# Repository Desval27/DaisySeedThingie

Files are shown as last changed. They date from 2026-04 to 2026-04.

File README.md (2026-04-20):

# Prototyping Carrier Board for the Daisy Seed™ 

https://electro-smith.com/products/daisy-seed

This PCB is designed to breakout all the PINs of the Daisy Seed along with additional components such as push buttons, LEDs, potentiometers, I<sup>2</sup>C, and SD card interfaces along with enough room for a typical 830 point breadboard.  

All 40 Daisy PINs are available on both sides of the board with those on the left being mirrored/inverted for additional flexibility.

[Interactive Bill of Materials (BOM)](https://github.com/Desval27/DaisySeedThingie/blob/main/bom/ibom.html)

## Ready to Order Gerber Files
- [Default](hardware/gerber_to_order/DaisySeedThingie_254.0x167.64mm_for_Default.zip)
- [Elecrow](hardware/gerber_to_order/DaisySeedThingie_254.0x167.64mm_for_Elecrow.zip)
- [FusionPCB](hardware/gerber_to_order/DaisySeedThingie_254.0x167.64mm_for_FusionPCB.zip)
- [JLCPCB](hardware/gerber_to_order/DaisySeedThingie_254.0x167.64mm_for_JLCPCB.zip)
- [PCBWay](hardware/gerber_to_order/DaisySeedThingie_254.0x167.64mm_for_PCBWay.zip)

## Status

Repository updated to Revision B.  Revision B is currently being tested.

Revsion A has several issues that are being corrected in Revision B.  Revision B is close to being finished.

- Due to footprint and learning issues no 3.5mm jacks are actually connected.  They can be hacked on the backside.
- All potentiometers are wired backwards.  CCW increases the voltage at the wiper while CW decreases it.

## Notes:
- Push buttons are connected on one side to GND to be used with input pullup GPIO pins.
- Potentiomenters are prewired on on the CW & CCW sides to +3V3 and GND.
- Audio in/out jacks are directly connected to the Seed's audio in/out pins.
   If the mono audio in jacks are used left audio in is normalized to right audio in so that they will both be available for processing by the seed if nothing is connected to right audio in.
- JST connectors are provided to breakout the Audio in/out and MIDI in/out signals to external jacks (1/4" Phono, 5-pin DIN, etc.).
- Jumpers are provided to change the configuration between TRS MIDI-A and TRS MIDI-B.  The default configuration is MIDI-A.  If MIDI-B is desired then the jumpers for MIDI-A need to be cut and those for MIDI-B bridged.

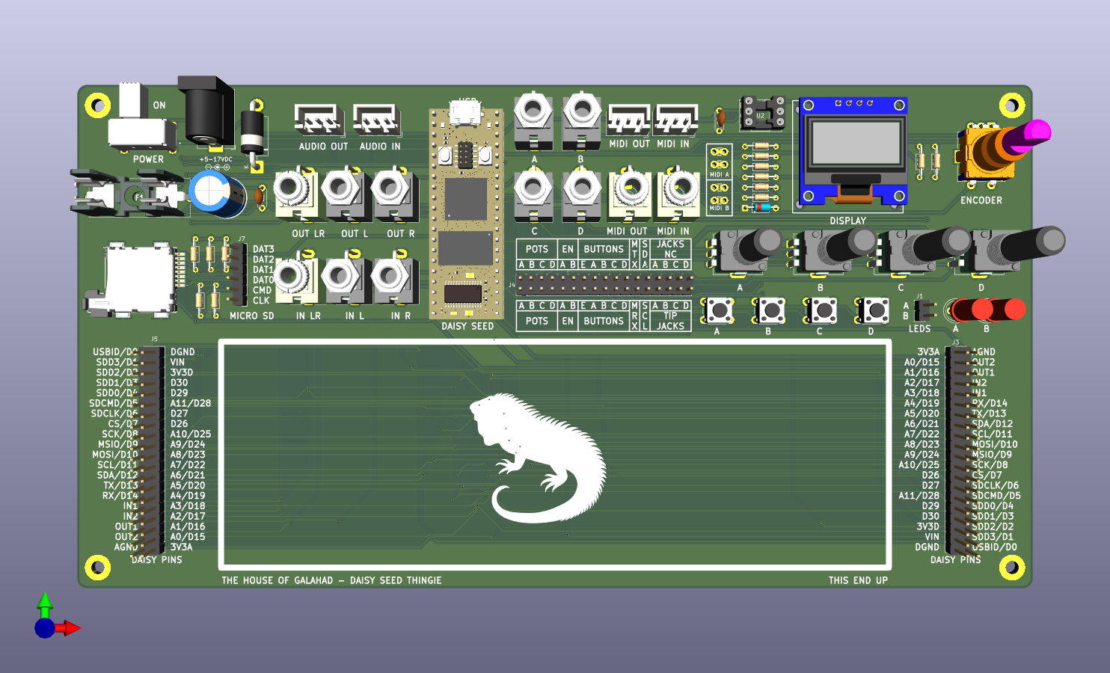
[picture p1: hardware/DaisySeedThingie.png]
Rendered PCB Image


## ⚠️ Disclaimer

This project is provided **"as is"**, without warranty of any kind, express or implied,
including but not limited to the warranties of merchantability, fitness for a
particular purpose, and noninfringement.

This is a DIY electronics project intended for educational and experimental use.
Use at your own risk.

The author assumes **no responsibility or liability** for any damage, injury, or loss
resulting from the use or misuse of this design, including but not limited to:

* Damage to connected equipment (Eurorack modules, power supplies, computers, etc.)
* Incorrect assembly or wiring
* Use with incompatible voltages or signal levels
* Personal injury

### Electrical Safety

This project may interface with:

* ±12V Eurorack power rails
* External control voltages (CV)
* Digital and analog circuitry

Improper handling may result in damage or unsafe conditions.

You are responsible for:

* Verifying all connections before powering the system
* Ensuring correct polarity of power connections
* Confirming voltage ranges and signal compatibility
* Using appropriate protection circuits where necessary

### No Guarantees

Schematics, PCB layouts, and code are provided for reference only.
They may contain errors, omissions, or design flaws.

**Always review and validate the design before building or using it.**

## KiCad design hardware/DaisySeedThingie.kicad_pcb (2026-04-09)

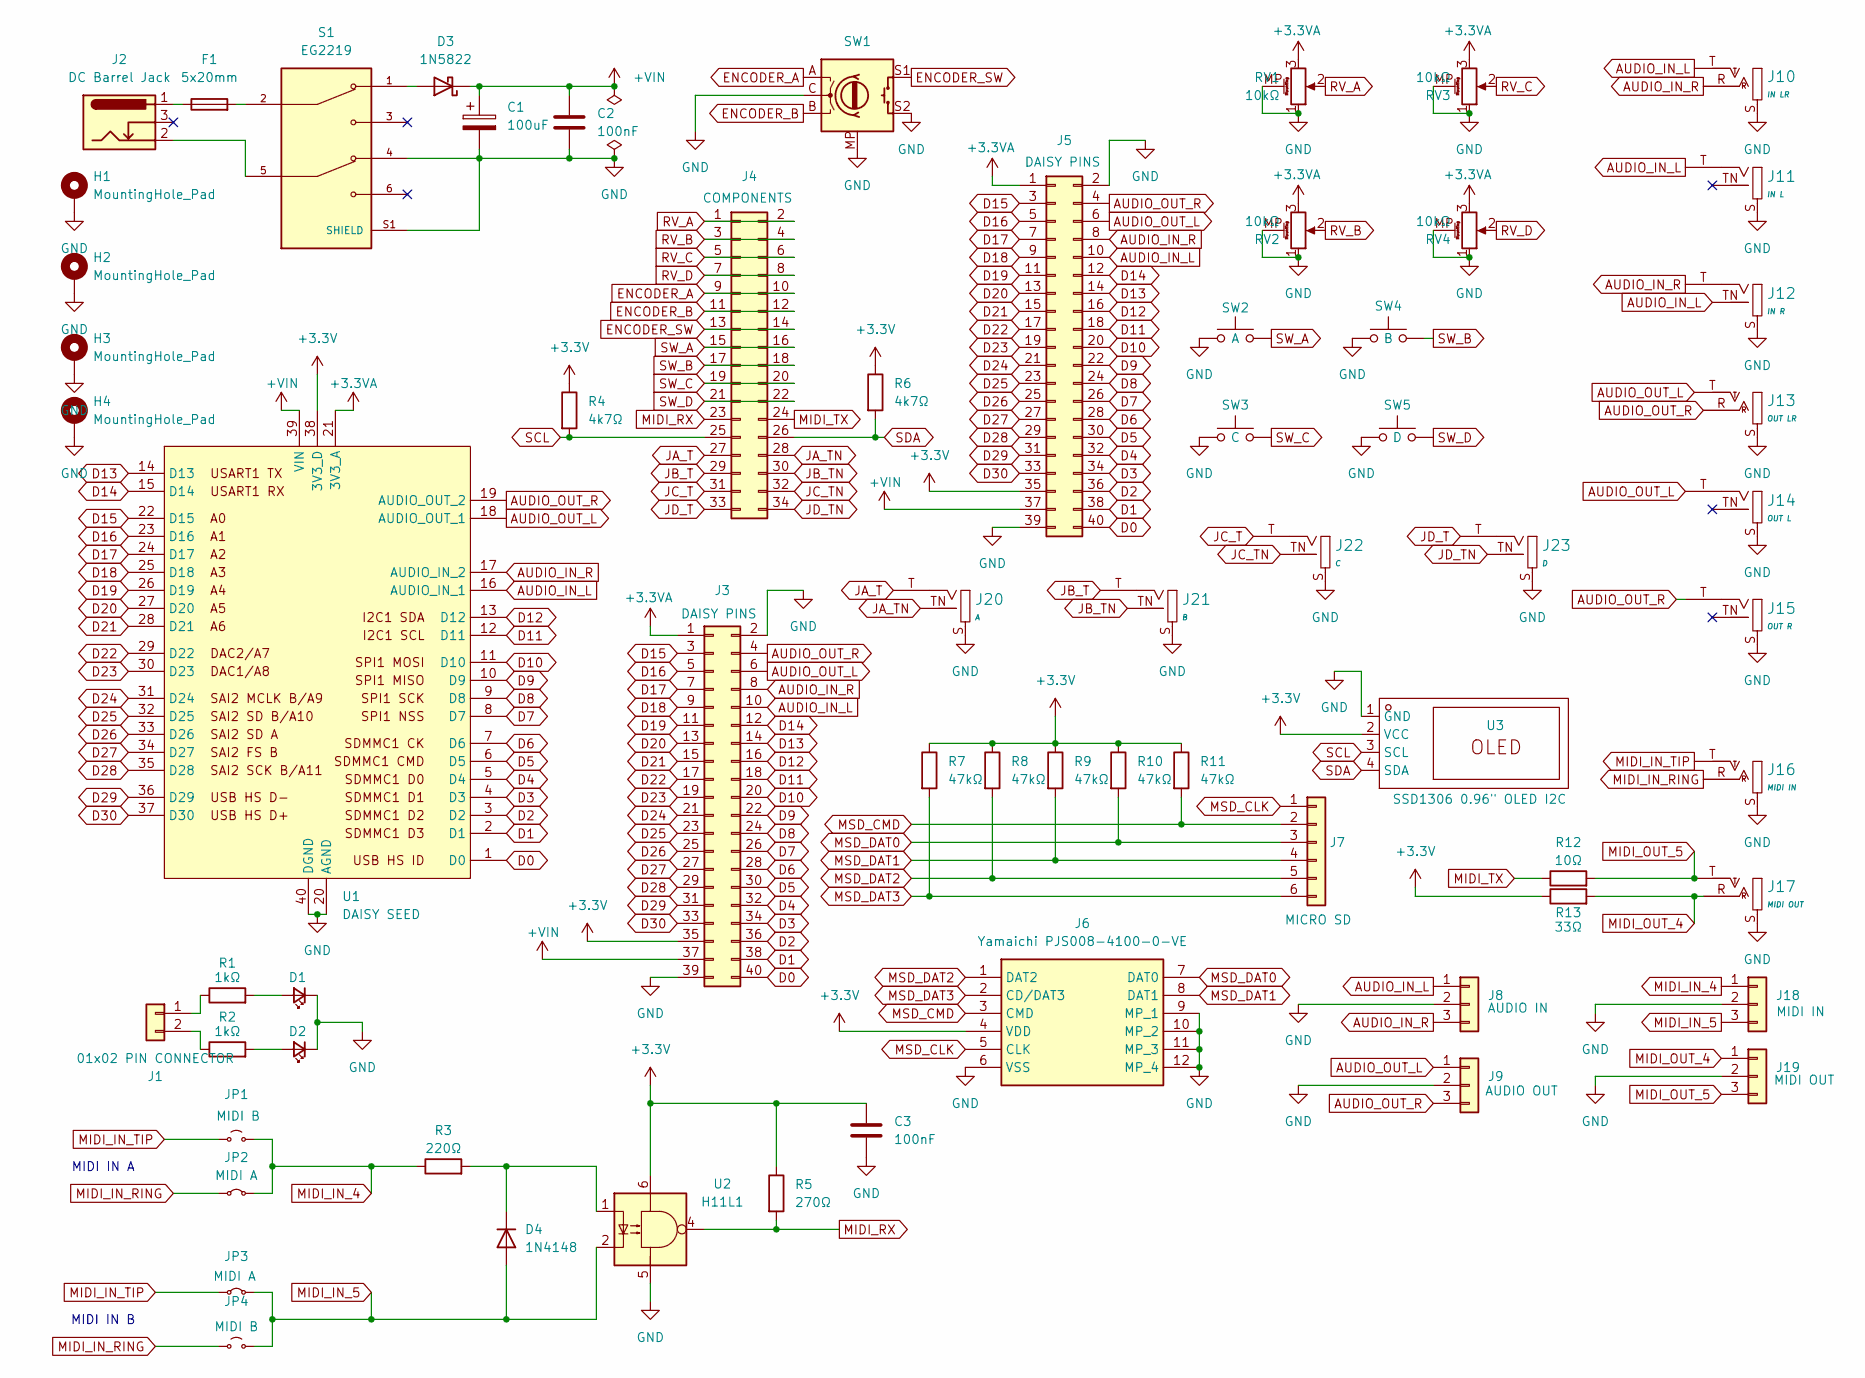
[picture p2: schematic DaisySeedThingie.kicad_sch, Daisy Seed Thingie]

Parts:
C1: 100uF; CP_Radial_D10.0mm_P5.00mm
C2, C3: 100nF; C_Disc_D4.3mm_W1.9mm_P5.00mm
D1, D2: RED; LED_D5.0mm_FlatTop
D3: 1N5822; D_DO-201AD_P15.24mm_Horizontal
D4: 1N4148; D_DO-35_SOD27_P7.62mm_Horizontal
F1: 5x20mm; 65600001409
H1, H2, H3, H4: MountingHole_Pad; MountingHole_3.2mm_M3_Pad
J1: 01x02 PIN CONNECTOR; PinHeader_1x02_P2.54mm_Vertical
J2: DC Barrel Jack; BarrelJack_Horizontal
J3, J5: 02x20 PIN CONNECTOR; PinHeader_2x20_P2.54mm_Vertical
J4: 02x17 PIN CONNECTOR; PinHeader_2x17_P2.54mm_Vertical
J6: Yamaichi PJS008-4100-0-VE; Yamaichi PJS00841000VE; Mouser Part Number 945-PJS008-4100-0-VE
J7: 01x06 PIN CONNECTOR; PinHeader_1x06_P2.54mm_Vertical
J8, J9, J18, J19: JST 01x03; JST_XH_B3B-XH-A_1x03_P2.50mm_Vertical
J10, J13, J16, J17: STEREO 3.5mm; Jack_3.5mm_QingPu_WQP-PJ366ST_Vertical; Part Number WQP-WQP419GR
J11, J12, J14, J15, J20, J21, J22, J23: MONO 3.5mm; Jack_3.5mm_QingPu_WQP-PJ398SM_Vertical; Part Number WQP-WQP518MA
JP1, JP4: JUMPER; Jumper_2_PTH_SMD_Combo-NO
JP2, JP3: JUMPER; Jumper_2_PTH_SMD_Combo-NC
R1, R2: 1kΩ; R_Axial_DIN0204_L3.6mm_D1.6mm_P7.62mm_Horizontal
R3: 220Ω; R_Axial_DIN0204_L3.6mm_D1.6mm_P7.62mm_Horizontal
R4, R6: 4k7Ω; R_Axial_DIN0204_L3.6mm_D1.6mm_P7.62mm_Horizontal
R5: 270Ω; R_Axial_DIN0204_L3.6mm_D1.6mm_P7.62mm_Horizontal
R7, R8, R9, R10, R11: 47kΩ; R_Axial_DIN0204_L3.6mm_D1.6mm_P7.62mm_Horizontal
R12: 10Ω; R_Axial_DIN0204_L3.6mm_D1.6mm_P7.62mm_Horizontal
R13: 33Ω; R_Axial_DIN0204_L3.6mm_D1.6mm_P7.62mm_Horizontal
RV1, RV2, RV3, RV4: 10kΩ; Potentiometer_Alps_RK09K_Single_Vertical
S1: EG2219; SW_EG2219; PARTREV B
SW1: EN11C; Rotary Encoder
SW2, SW3, SW4, SW5: SW_PUSH_6mm
U1: DAISY SEED; DAISY_SEED
U2: H11L1; DIP-6_W7.62mm_Socket_LongPads
U3: SSD1306 0.96" OLED I2C; 0.96 Inch OLED I2C Display Module; Manufacturer Part HS13L03B2C01; LCSC Part Name 1.3'1.3寸 128*64 OLED显示屏 I2C通讯 SH1106 蓝光

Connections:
+3.3V: C3.1, J3.35, J5.35, J6.4 (VDD), R4.1, R5.1, R6.1, R7.1, R8.1, R9.1, R10.1, R11.1, R13.1, U1.38 (3V3_D), U2.6, U3.2 (VCC)
+3.3VA: J3.1, J5.1, RV1.3, RV2.3, RV3.3, RV4.3, U1.21 (3V3_A)
+VIN: C1.1, C2.1, D3.1 (K), J3.37, J5.37, U1.39 (VIN)
AUDIO_IN_L: J3.10, J5.10, J8.1, J10.T (SIG), J11.T (SIG), J12.TN (SW), U1.16 (AUDIO_IN_1)
AUDIO_IN_R: J3.8, J5.8, J8.3, J10.R (SW), J12.T (SIG), U1.17 (AUDIO_IN_2)
AUDIO_OUT_L: J3.6, J5.6, J9.1, J13.T (SIG), J14.T (SIG), U1.18 (AUDIO_OUT_1)
AUDIO_OUT_R: J3.4, J5.4, J9.3, J13.R (SW), J15.T (SIG), U1.19 (AUDIO_OUT_2)
D0: J3.40, J5.40, U1.1 (D0)
D1: J3.38, J5.38, U1.2 (D1)
D2: J3.36, J5.36, U1.3 (D2)
D3: J3.34, J5.34, U1.4 (D3)
D4: J3.32, J5.32, U1.5 (D4)
D5: J3.30, J5.30, U1.6 (D5)
D6: J3.28, J5.28, U1.7 (D6)
D7: J3.26, J5.26, U1.8 (D7)
D8: J3.24, J5.24, U1.9 (D8)
D9: J3.22, J5.22, U1.10 (D9)
D10: J3.20, J5.20, U1.11 (D10)
D11: J3.18, J5.18, U1.12 (D11)
D12: J3.16, J5.16, U1.13 (D12)
D13: J3.14, J5.14, U1.14 (D13)
D14: J3.12, J5.12, U1.15 (D14)
D15: J3.3, J5.3, U1.22 (D15)
D16: J3.5, J5.5, U1.23 (D16)
D17: J3.7, J5.7, U1.24 (D17)
D18: J3.9, J5.9, U1.25 (D18)
D19: J3.11, J5.11, U1.26 (D19)
D20: J3.13, J5.13, U1.27 (D20)
D21: J3.15, J5.15, U1.28 (D21)
D22: J3.17, J5.17, U1.29 (D22)
D23: J3.19, J5.19, U1.30 (D23)
D24: J3.21, J5.21, U1.31 (D24)
D25: J3.23, J5.23, U1.32 (D25)
D26: J3.25, J5.25, U1.33 (D26)
D27: J3.27, J5.27, U1.34 (D27)
D28: J3.29, J5.29, U1.35 (D28)
D29: J3.31, J5.31, U1.36 (D29)
D30: J3.33, J5.33, U1.37 (D30)
ENCODER_A: J4.9, J4.10, SW1.A
ENCODER_B: J4.11, J4.12, SW1.B
ENCODER_SW: J4.13, J4.14, SW1.S1
GND: C1.2, C2.2, C3.2, D1.1 (K), D2.1 (K), H1.1, H2.1, H3.1, H4.1, J3.2, J3.39, J5.2, J5.39, J6.6 (VSS), J6.9 (MP_1), J6.10 (MP_2), J6.11 (MP_3), J6.12 (MP_4), J8.2, J9.2, J10.S (SHEILD), J11.S (SHEILD), J12.S (SHEILD), J13.S (SHEILD), J14.S (SHEILD), J15.S (SHEILD), J16.S (SHEILD), J17.S (SHEILD), J18.2, J19.2, J20.S (SHEILD), J21.S (SHEILD), J22.S (SHEILD), J23.S (SHEILD), RV1.1, RV1.MP (MountPin), RV2.1, RV2.MP (MountPin), RV3.1, RV3.MP (MountPin), RV4.1, RV4.MP (MountPin), S1.4, S1.S1 (SHIELD), S1.S2 (SHIELD), S1.S3 (SHIELD), S1.S4 (SHIELD), SW1.C, SW1.MP, SW1.S2, SW2.1, SW3.1, SW4.1, SW5.1, U1.20 (AGND), U1.40 (DGND), U2.5, U3.1 (GND)
JA_T: J4.27, J20.T (SIG)
JA_TN: J4.28, J20.TN (SW)
JB_T: J4.29, J21.T (SIG)
JB_TN: J4.30, J21.TN (SW)
JC_T: J4.31, J22.T (SIG)
JC_TN: J4.32, J22.TN (SW)
JD_T: J4.33, J23.T (SIG)
JD_TN: J4.34, J23.TN (SW)
MIDI_IN_4: J18.1, JP1.2 (B), JP2.2 (B), R3.1
MIDI_IN_5: D4.2 (A), J18.3, JP3.2 (B), JP4.2 (B), U2.2
MIDI_IN_RING: J16.R (SW), JP2.1 (A), JP4.1 (A)
MIDI_IN_TIP: J16.T (SIG), JP1.1 (A), JP3.1 (A)
MIDI_OUT_4: J17.R (SW), J19.1, R13.2
MIDI_OUT_5: J17.T (SIG), J19.3, R12.2
MIDI_RX: J4.23, R5.2, U2.4
MIDI_TX: J4.24, R12.1
MSD_CLK: J6.5 (CLK), J7.1
MSD_CMD: J6.3 (CMD), J7.2, R11.2
MSD_DAT0: J6.7 (DAT0), J7.3, R10.2
MSD_DAT1: J6.8 (DAT1), J7.4, R9.2
MSD_DAT2: J6.1 (DAT2), J7.5, R8.2
MSD_DAT3: J6.2 (CD/DAT3), J7.6, R7.2
unnamed: D1.2 (A), R1.2
unnamed: D2.2 (A), R2.2
unnamed: D3.2 (A), S1.1
unnamed: D4.1 (K), R3.2, U2.1
unnamed: F1.1, J2.1
unnamed: F1.2, S1.2
unnamed: J1.1, R1.1
unnamed: J1.2, R2.1
unnamed: J2.2, S1.5
RV_A: J4.1, J4.2, RV1.2
RV_B: J4.3, J4.4, RV2.2
RV_C: J4.5, J4.6, RV3.2
RV_D: J4.7, J4.8, RV4.2
SCL: J4.25, R4.2, U3.3 (SCL)
SDA: J4.26, R6.2, U3.4 (SDA)
SW_A: J4.15, J4.16, SW2.2
SW_B: J4.17, J4.18, SW4.2
SW_C: J4.19, J4.20, SW3.2
SW_D: J4.21, J4.22, SW5.2

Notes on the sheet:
MIDI IN A
MIDI IN B

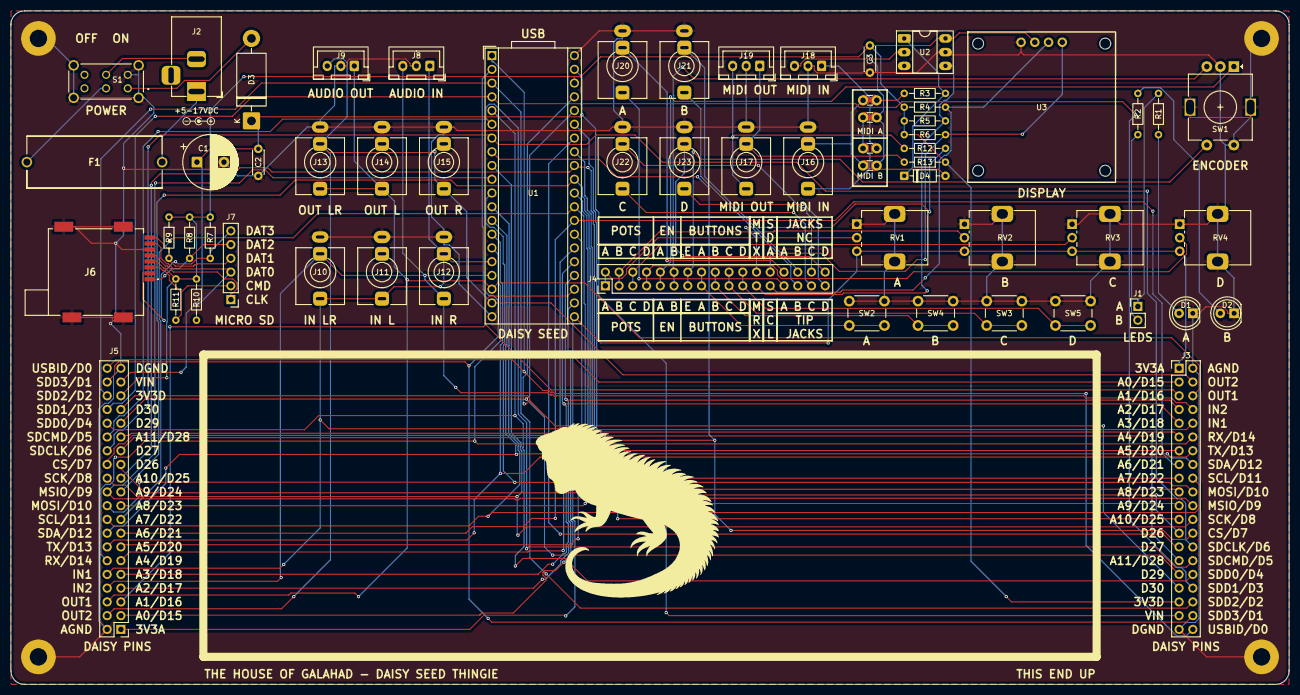
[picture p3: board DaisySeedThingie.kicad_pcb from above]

Board: 2 copper layers, 236.2 x 124.5 mm, 65 parts (0 on the bottom side), 83 nets.

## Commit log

2026-04-06 Initial Revision B
    [DaisySeedThingie.kicad_pcb, DaisySeedThingie.kicad_sch]
2026-04-06 Delete gerber_to_order/DaisySeedThingie_254.0x167.64mm_for_JLCPCB.zip
    Older Revision A board with numerous errors.
2026-04-06 Enhance README formatting and add BOM link
    Updated README with improved formatting and added interactive BOM link.
2026-04-06 Fix BOM link in README.md
    Updated the link to the Interactive Bill of Materials (BOM) to point to the correct GitHub URL.
2026-04-06 Fix image path for rendered PCB in README
    Updated the image path for the rendered PCB in the README.
2026-04-06 Restore after bad merge
    [DaisySeedThingie.kicad_pcb, DaisySeedThingie.kicad_sch]
2026-04-20 Refreshed Gerbers
2026-04-20 Added Gerber to Order Links
